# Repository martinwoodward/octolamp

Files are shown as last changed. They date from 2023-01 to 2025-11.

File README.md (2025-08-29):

# Octolamp
A 3D printable, GitHub infused, WiFi enabled smart light powered by [WLED](https://kno.wled.ge/) and compatible with [Home Assistant](https://www.home-assistant.io/)

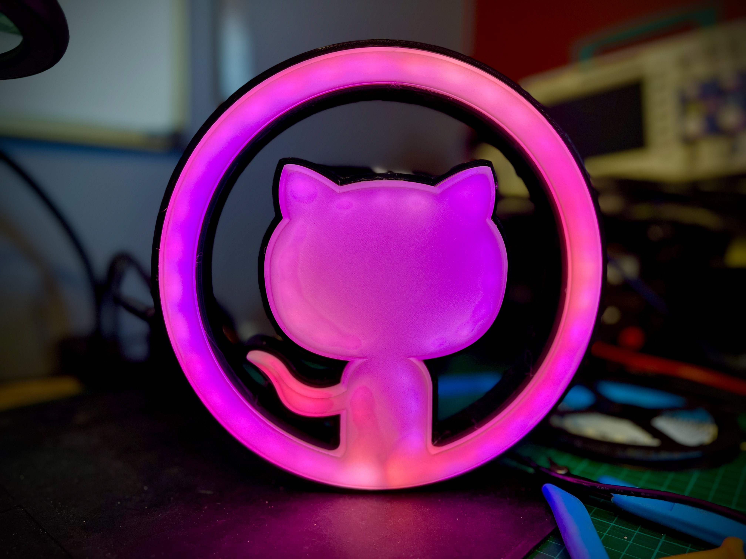
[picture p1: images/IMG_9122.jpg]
Picture of a fully constructed Octolamp


### Components

To build the Octolamp, you'll need access to a 3D printer, soldering iron and the following components:

- [Black PLA Filament](https://amzn.to/3CTo54W) (for the base) - [[US](https://amzn.to/3CTo54W)] [[UK](https://amzn.to/3w7fCXX)]
- [White PLA Filament](https://amzn.to/3GKObIz) (for the inner body and reflector) - [[US](https://amzn.to/3GKObIz)] [[UK](https://amzn.to/3XBNVSM)]
- WS2812B LED Strip, 60 LEDs per meter, just under 2m worth but usually sold in spools of 5m - [[US](https://amzn.to/3XwWnCT)] [[UK](https://amzn.to/3QKIzm6)]
- ESP8266 NodeMCU D1 Mini Module (or similar clone or other WLED compatible device) - [[US](https://amzn.to/3koQwS0)] [[UK](https://amzn.to/3kmp473)]
- USB lead (Micro or Type-C depending on the model of D1 Mini you have purchased, usually Micro-USB) [[US](https://amzn.to/3CTpqsl)] [[UK](https://amzn.to/3XxulY2)]

If you are looking for recommended links to buy these somewhere locally then please see [Purchasing Links](#purchasing-links) below.

Assuming you already have the PLA filament and a spare USB lead, the construction cost for the electrical components works out at <$20 per lamp.

### Instructions

The lamp itself consists of 3 printable parts, printed in regular PLA on a printer with greater than a 210mmx210mm print bed (the popular [Ender 3](https://amzn.to/3CRwSUQ) or [Prusa i3](https://amzn.to/3ZxlHdI) should both work, this was tested with an [Ender 3 S1](https://amzn.to/3CRwSUQ))

All models are designed to be printed without supports. I used a 10% gyroid infill.

The 3 components are:
- [Black base](models/octolamp_black_outer.stl)
- [White reflector](models/octolamp_white_reflector.stl)
- [White inner](models/octolamp_white_inner.stl)

When constructed they snap-fit together as shown.

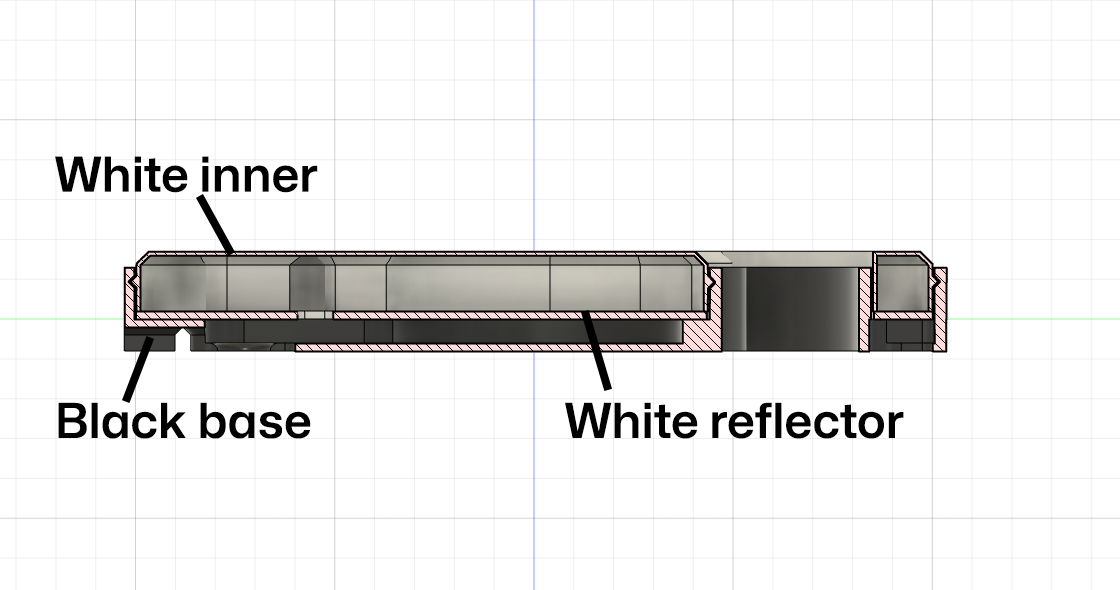
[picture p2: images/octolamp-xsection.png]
Cross-section of the Octolamp


When you have assembled your 3d printed parts you can begin contruction.

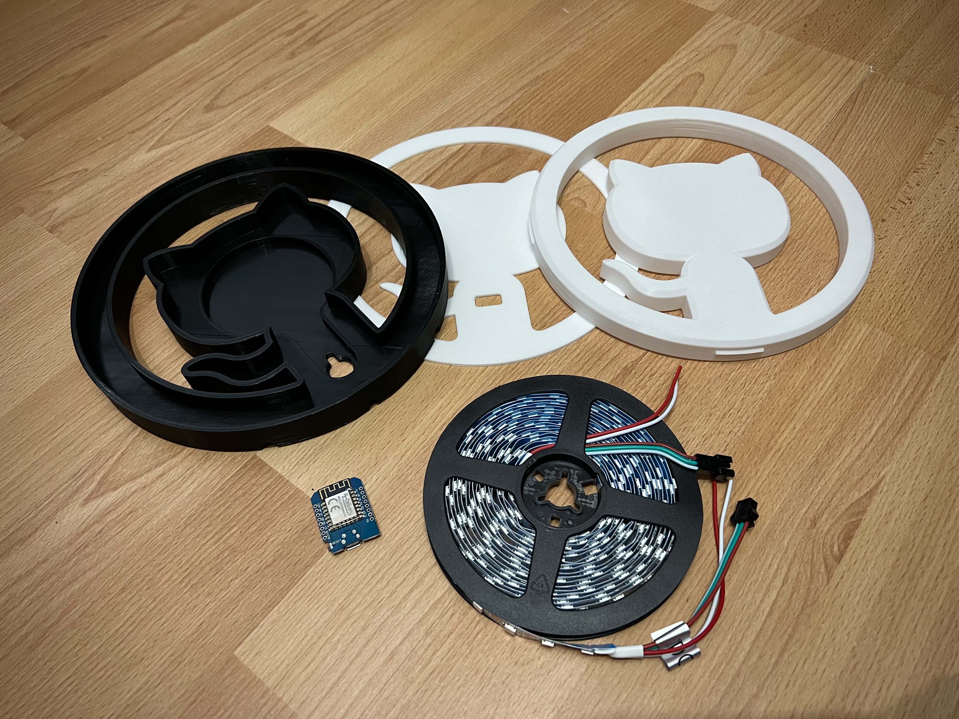
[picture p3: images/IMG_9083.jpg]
Component parts for the Octolamp build


#### Step 1 - Install WLED

First, you'll want to flash your D1 Mini device with [WLED](https://kno.wled.ge/) and then configure it to connect to your WiFi network. the [WLED project](https://kno.wled.ge/) is an open source firmware for many embedded devices that allow you to create beautiful LED displays and network them together. There are controller apps for iOS and Android and it is also fully compatible with the popular [Home Assistant](https://www.home-assistant.io/) software meaning that once built you can control your lamp from anywhere and build any number of automations so that it flashes when someone stars your GitHub repo, changes color when your build breaks or switches on and off with your office lights. 

Note that for large LED displays you can need significant power, you'll also likely want a controller that has a level shifter to send a reliable 5v signal for data to your LED strip. However as we're only powering 100 or so LEDs you can get away with pulling the power and data directly from the pins of an inexpensive D1 Mini.

The quickest and easiest way to install WLED on your D1 Mini is to plug it into the USB socket on your computer and then visit the [WLED web installer site](https://install.wled.me/).

- [https://install.wled.me/](https://install.wled.me/)

Flash the device with the latest build of WLED, configure the device to connect to your WiFi network and then you are ready to go.

#### Step 2 - Stick the LED Strip to the White Inner

The White Inner component acts as the guide for the flexible LED strip as well as the diffuser for the lights which are stuck to the side. You only need the +5v, G and Data pins so snip off any additional power lines that might come with your strip or solder on new wires to the strip if yours didn't come with pre-soldered wires.  Remove the plastic from the adhesive backing and start sticking at the bottom middle, looping around the outside then over to the inside and finally around the central part. Cut at the marked lines when you are finally done. Depending on your LED strip, the central part may require some additional adhesive, such as PLA friendly glue, to remain in place due to the reverse bend going from Octocat's body to head.

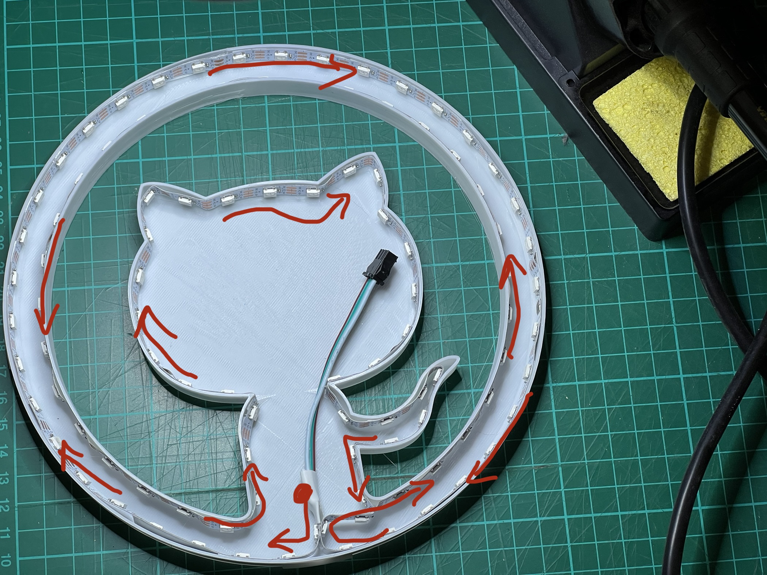
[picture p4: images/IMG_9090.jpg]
Path of the LED strip


When finished you should have around 100 LEDs in your lamp, but it's worth counting at this point as you'll need the exact number later (depending how I did my sticking I've used anything from 99 to 105)

#### Step 3 - Add the Reflector
Next, feed the wires through the hole in the reflector. If you are using plugs to connect your strip and controller then you can do this at any time but if you are soldering the strip directly to the controller then you need to do it now.

#### Step 4 - Solder LED Strip to D1 Mini
Rather than use plugs, I solder my strip directly to my D1 Mini, but you can use connectors if you wish.  Connect the +5v and G lines to the corresponding pins on the D1 Mini and the data line to D4 (just above the +5v and G pins).

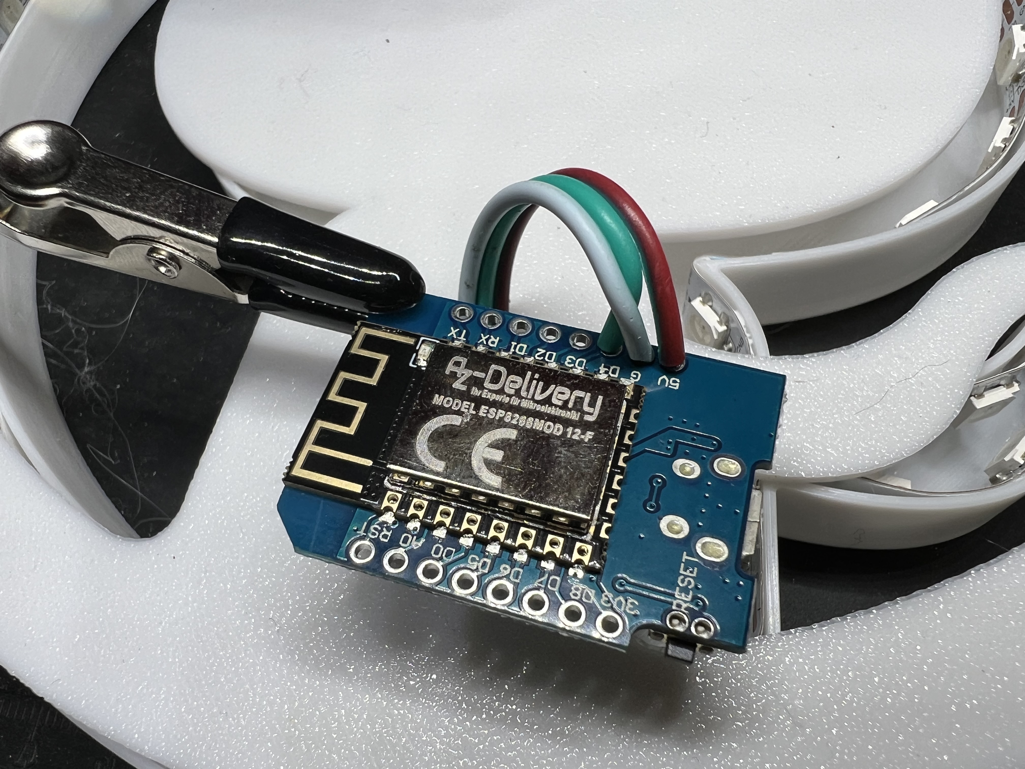
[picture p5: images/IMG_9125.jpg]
The wires from the LED strip soldered to the D1 Mini


#### Step 5 - Assemble
Next up, feed your USB lead through the back of the black outer body and connect it to your D1 Mini.  Place the D1 Mini in the small inlaid portion in the center of the lamp. Then drop in the reflector and finally place the white inner onto it, and snap fit into the black outer body. This should force the white reflector down which then also secures the electronics in place.  Power up your device and at this point about half of your LEDs should be glowing orange.

#### Step 6 - Connect to WLED and configure display
All the rest of the configuration is configuring WLED for your device.  Connect using the IP address from installation time, then go to Config, LED Preferences and update the Length of the LED strip to be the number of LEDs you installed in Step 2 (for me that's typically between 99 - 105).  When you press Save the rest of your LEDs should be glowing orange.

You can now configure your light display with the amazing flexibility of WLED. Once you have your favorite setting, store it as a preset and then go back to the LED Preferences and scroll down to Defaults where you can set which preset it displayed when the lamp is powered on (i.e. Preset 1 instead of the default orange in Preset 0)

#### Step 7 - Share your makes!
That's it!  You are now done but I'd love to see pictures of your built and assembled lamps.  Feel free to share pictures of them [in discussions here](https://github.com/martinwoodward/octolamp/discussions) or on social media and tag me on them [martinwoodward@hachyderm.io](https://hachyderm.io/@martinwoodward) on Mastodon or [@martinwoodward](https://twitter.com/martinwoodward) on Twitter and other socials

### Notes

I've tried to make the model super flexible so it includes ways to mount the lamp to a wall and different USB cable routing options.

The copyright for the invertocat logo belongs to GitHub. For acceptable use of that logo see the [GitHub logo usage guidelines](https://github.com/logos).

### Purchasing Links
The fun part of this project is making it yourself, the lamp isn't officially sold pre-assembled (and the license is non-commercial use only so they shouldn't be doing that).  But if you want to buy the components to make this them then the following components have been used and recommended by community members. Note some of these links make use of affiliate programs but they should always be linking to components the community trust.

#### United States
- [Black PLA Filament](https://amzn.to/3CTo54W) (for the base)
- [White PLA Filament](https://amzn.to/3GKObIz) (for the inner body and reflector)
- [WS2812B LED Strip, 60 LEDs per meter](https://amzn.to/3XwWnCT), just under 2m worth but usually sold in spools of 5m 
- [ESP8266 NodeMCU D1 Mini Module](https://amzn.to/3koQwS0) (or similar clone or other WLED compatible device)
- [Ender 3](https://amzn.to/3YjmLkD) S1 3D Printer

#### United Kingdom
- [Black PLA Filament](https://amzn.to/3w7fCXX) (for the base)
- [White PLA Filament](https://amzn.to/3XBNVSM) (for the inner body and reflector)
- [WS2812B LED Strip, 60 LEDs per meter](https://amzn.to/3QKIzm6), just under 2m worth but usually sold in spools of 5m 
- [ESP8266 NodeMCU D1 Mini Module](https://amzn.to/3kmp473) (or similar clone or other WLED compatible device)
- [Ender 3](https://amzn.to/3xcwoW9) S1 3D Printer

#### Singapore
- [WS2812B LED Strip, 60 LEDs per meter](https://s.lazada.sg/s.0zKLk), just under 2m worth but usually sold in spools of 5m 
- [ESP8266 NodeMCU D1 Mini Module](https://shp.ee/9gxtxxn) (or similar clone or other WLED compatible device)

#### Australia
- [WS2812B LED Strip, 60 LEDs per meter](https://www.jaycar.com.au/duinotech-arduino-compatible-w2812b-rgb-led-strip-2m/p/XC4390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) contains 2m, with 120 LEDs with connectors installed at ends and wires with connector for soldering to board
- [ESP8266 Wi-Fi D1 Mini Module](https://www.jaycar.com.au/duinotech-wi-fi-mini-esp8266-main-board/p/XC3802) or similar clone or other WLED compatible device. Note: This option has pre-installed IO header strips so some desoldering may be required

### Link to these instructions
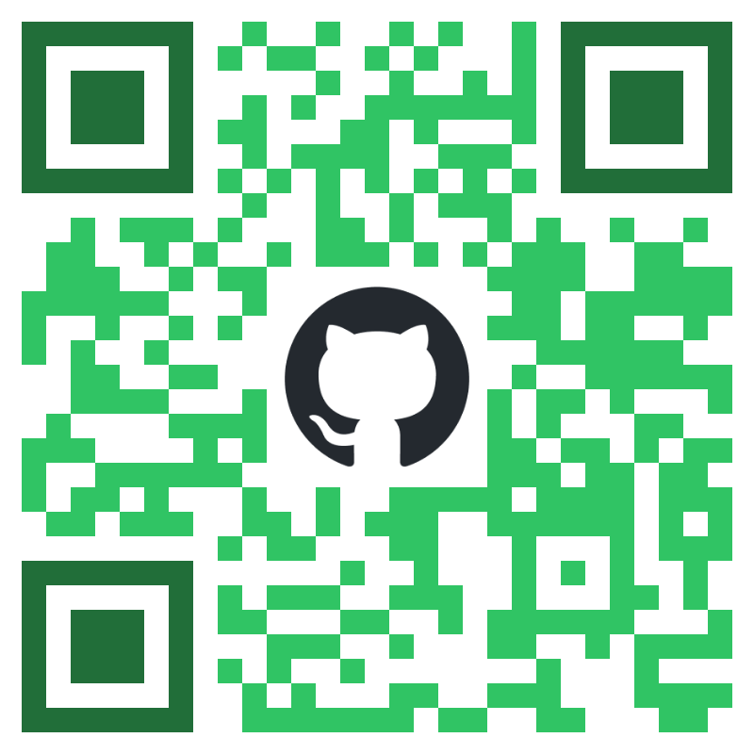
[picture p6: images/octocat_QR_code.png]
QR Code to these instructions


Instructions: https://github.com/martinwoodward/octolamp

An 85% scale of the Lamp is available [here](models/octolamp_multipart_A1_mini.3mf) for those with smaller print beds.

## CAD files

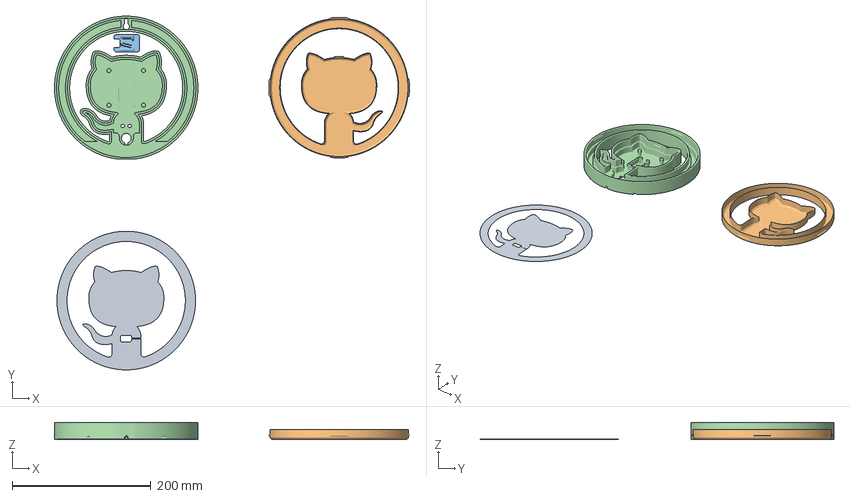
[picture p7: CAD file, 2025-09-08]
models/octolamp_multipart_mini_sparkle_motion.3mf
512.2 x 510.4 x 25.0 mm
White Reflector.stl
White Inner.stl
Black Outer Sparle Motion Top.stl
Black Bottom Mini Sparkle Motion.stl

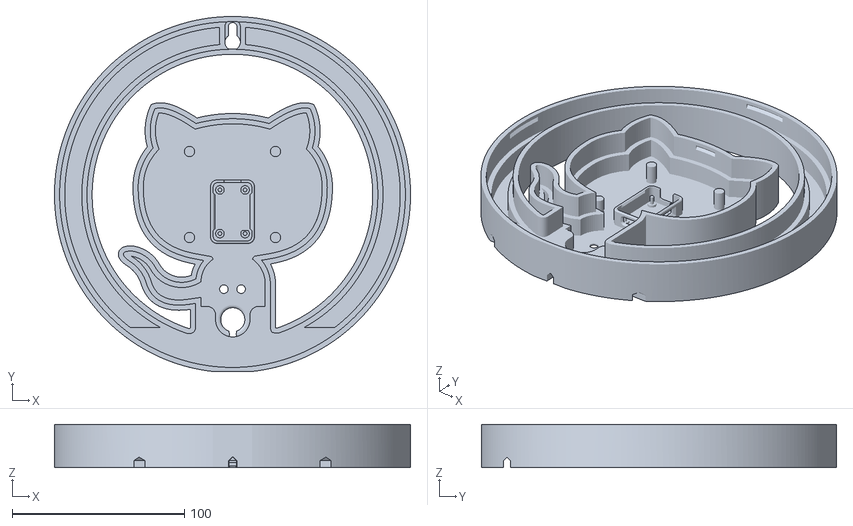
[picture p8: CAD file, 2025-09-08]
models/octolamp_black_outer_mini_sparkle_motion.stl
207.0 x 206.4 x 25.0

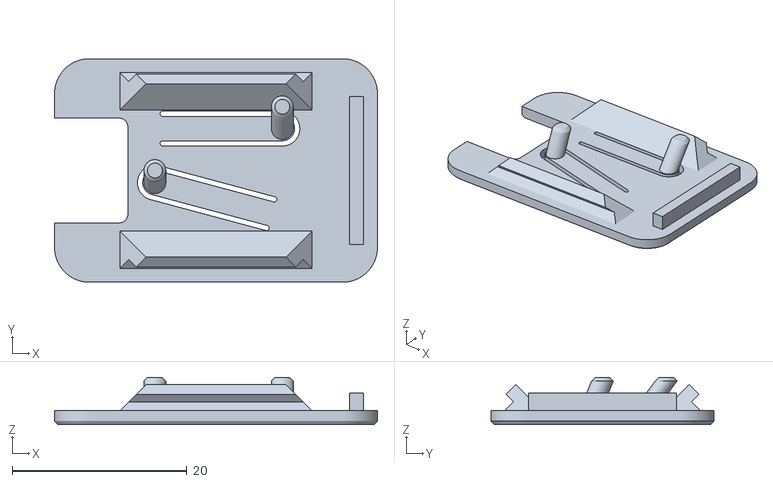
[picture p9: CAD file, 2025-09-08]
models/octolamp_black_outer_mini_sparkle_motion_top.stl
37.0 x 25.6 x 5.40

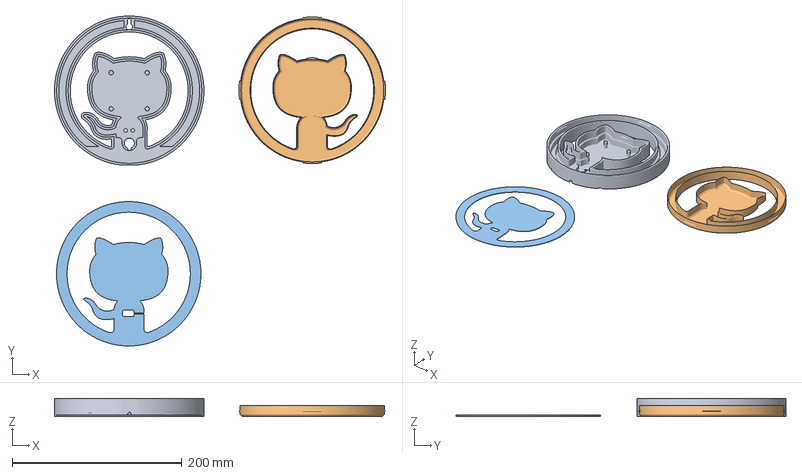
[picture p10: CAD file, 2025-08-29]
models/octolamp_multipart_A1_mini.3mf
389.6 x 388.4 x 21.2 mm
Black Outer.stl
octolamp_white_inner.stl
octolamp_white_reflector.stl

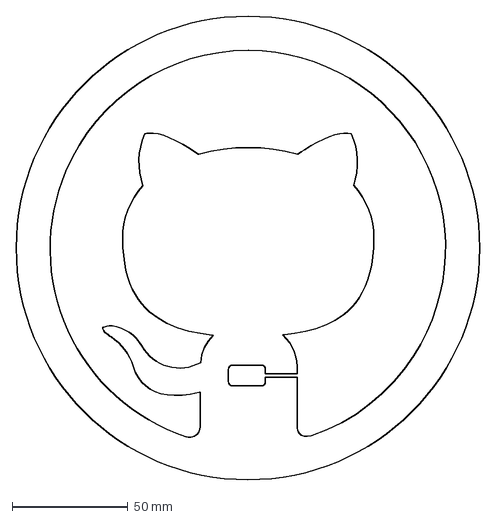
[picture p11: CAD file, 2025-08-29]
models/octolamp_white_reflector_laser.dxf
200.0 x 200.0 mm

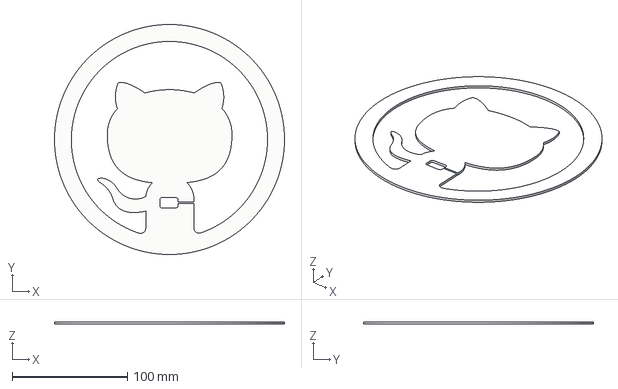
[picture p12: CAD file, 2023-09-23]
models/octolamp_white_reflector.3mf
200.0 x 200.0 x 2.00 mm

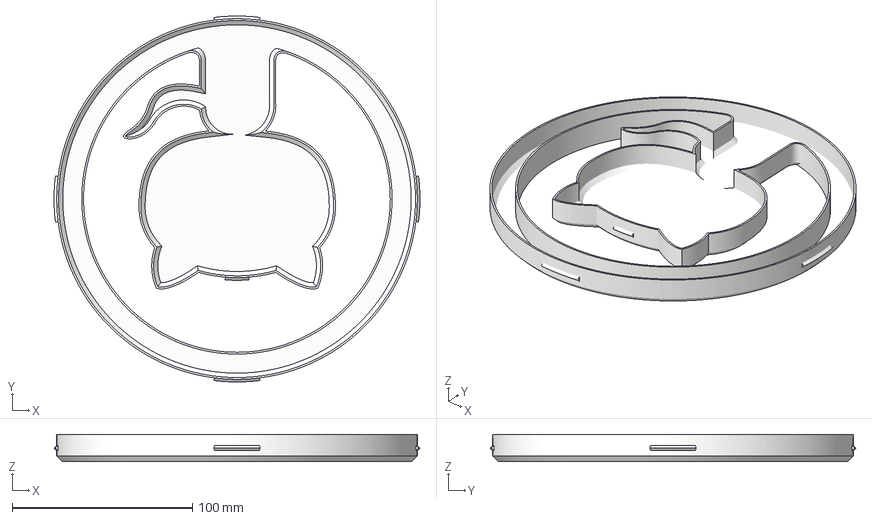
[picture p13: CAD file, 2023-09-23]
models/octolamp_white_inner.3mf
203.0 x 203.0 x 15.0 mm

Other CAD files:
models/octolamp_black_outer.3mf
models/octolamp_multipart.3mf
models/octolamp.f3d
models/octolamp_black_outer.stl
models/octolamp_white_inner.stl
models/octolamp_white_reflector.stl

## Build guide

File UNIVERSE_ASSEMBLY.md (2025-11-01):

# Assembling Your Octolamp Kit

Your Octolamp kit includes all the components you need to assemble your very own Octolamp! Follow these step-by-step instructions to get your lamp up and running.

You can find a video version of this tutorial here: https://youtu.be/Ya8gMkDxdD4 

Powered by an [Adafruit Sparkle Motion Mini](https://www.adafruit.com/product/6314) microcontroller, your Octolamp features an LED strip that is smarter than it may first appear.

## What is Included
- [Black base (Sparkle Motion Edition)](https://github.com/martinwoodward/octolamp/blob/main/models/octolamp_black_outer_mini_sparkle_motion.stl)
- [Black Controller cover](https://github.com/martinwoodward/octolamp/tree/main/models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)
- [White LED Holder](https://github.com/martinwoodward/octolamp/blob/main/models/octolamp_white_inner.stl)
- [White reflector](https://github.com/martinwoodward/octolamp/blob/main/models/octolamp_white_reflector.stl)
- Screwdriver
- [Adafruit Sparkle Motion Mini Microcontroller](https://www.adafruit.com/product/6314)
- USB cable
- LED cable
- LED strip (IP30 60 LED's per metre)
- Cable tie

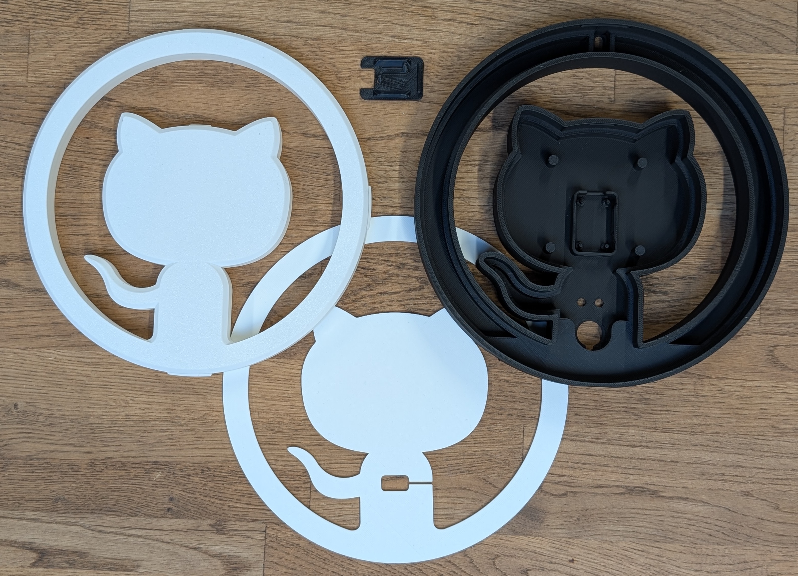
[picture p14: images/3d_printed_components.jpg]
3D printed components of the Octolamp including white inner shell, black outer cover, black base, and white reflector arranged on a surface

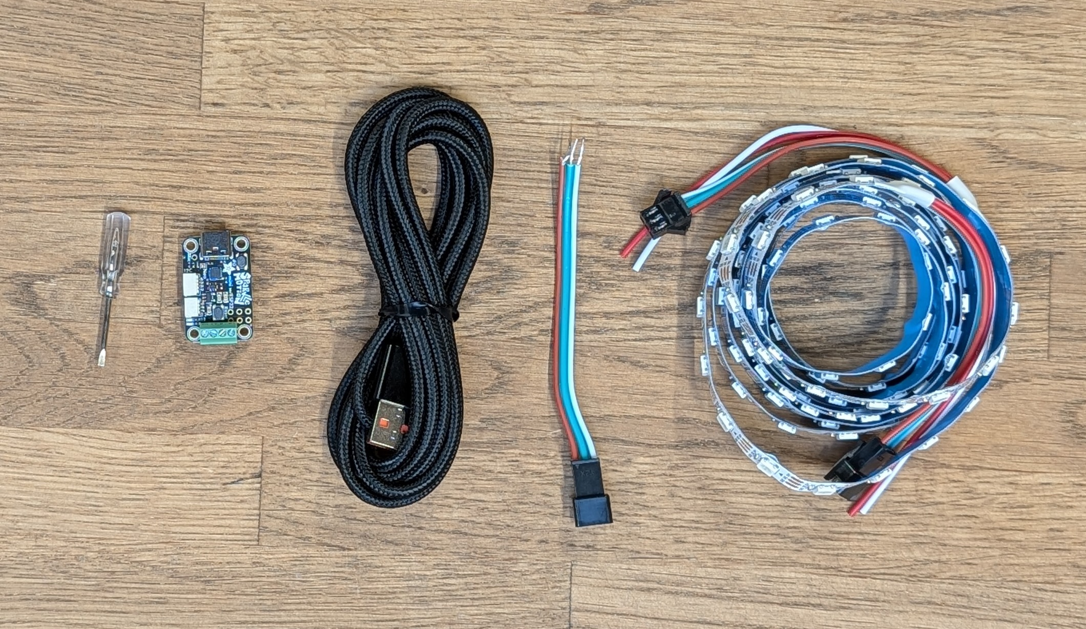
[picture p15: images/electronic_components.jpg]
Electronic components for the Octolamp including microcontroller board, USB cable, LED cable, and LED strip laid out ready for assembly


## Step 1: Connect the LED Cable to the Microcontroller
1. Use the screwdriver to loosen the first, third, and fourth terminals on the microcontroller.
2. From left to right, insert the red, green, and white wires of the LED cable into the respective terminals.
3. Tighten the terminals using the screwdriver.

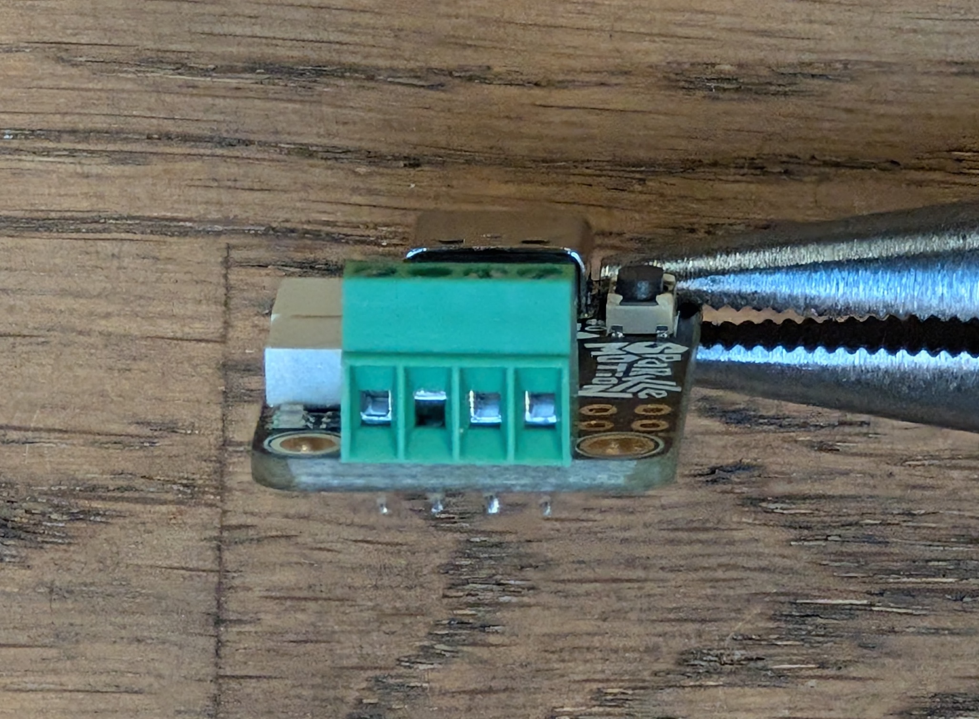
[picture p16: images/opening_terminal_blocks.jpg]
Close-up view of microcontroller terminal blocks being loosened with a screwdriver, showing the screw terminals in their open position ready for wire insertion

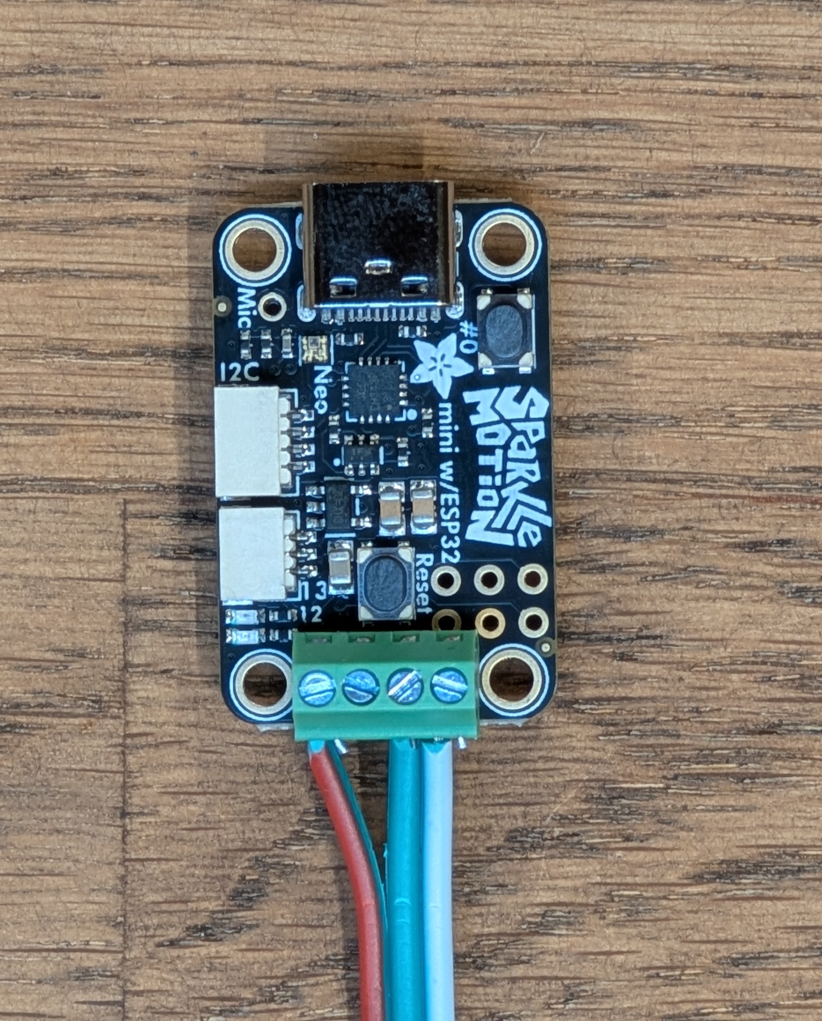
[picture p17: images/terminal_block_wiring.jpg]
Microcontroller terminal blocks with red, green, and white LED wires properly inserted and secured in the first, third, and fourth terminals from left to right


## Step 2: Test the LED Connection
1. **Important:** Uncoil the LED strip completely. Powering LEDs while tightly coiled will cause overheating.
2. Connect the LED cable to the LED strip. The cable should connect to the end with arrows pointing **away** from the connector.
3. Plug the USB cable into the microcontroller and connect to a power supply.
4. The LED's should now light up, either orange or green. 
5. If your LEDs do not turn on, check your connections.
6. If you are still having trouble, ask for help!

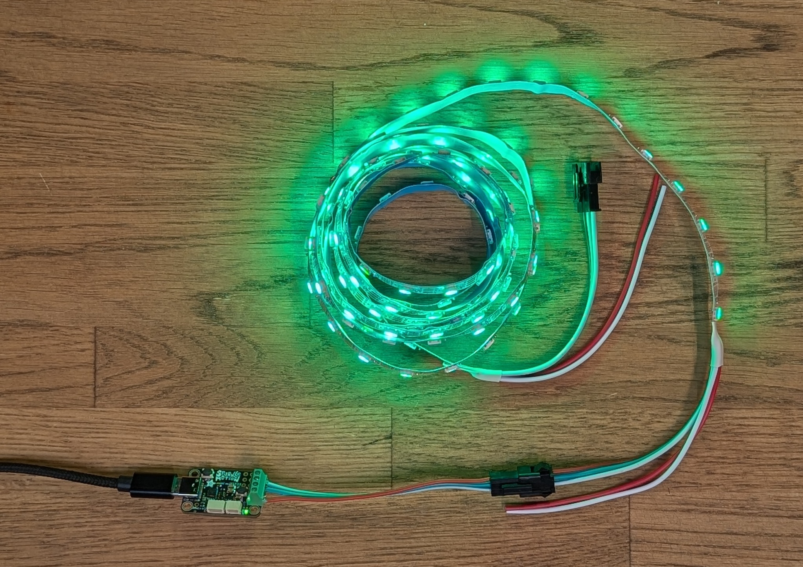
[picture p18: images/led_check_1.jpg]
LED strip connected and powered on, displaying bright green lights across most of the strip with the last few LEDs remaining off as expected during testing


## Step 3: Install the LED Strip Around the Outer Ring
1. Peel off the beginning of the LED strip's adhesive backing.
2. Press the start of the LED strip against the inside wall of the outer ring, at the base of Mona.
3. Continue around the inside wall of the outer ring, peeling off backing as you go.
4. Firmly press the strip against the ring frequently to ensure good adhesion.
5. Trim the backing paper if it gets in your way.
6. When you complete the outer ring, you should be back where you started at the base of Mona.

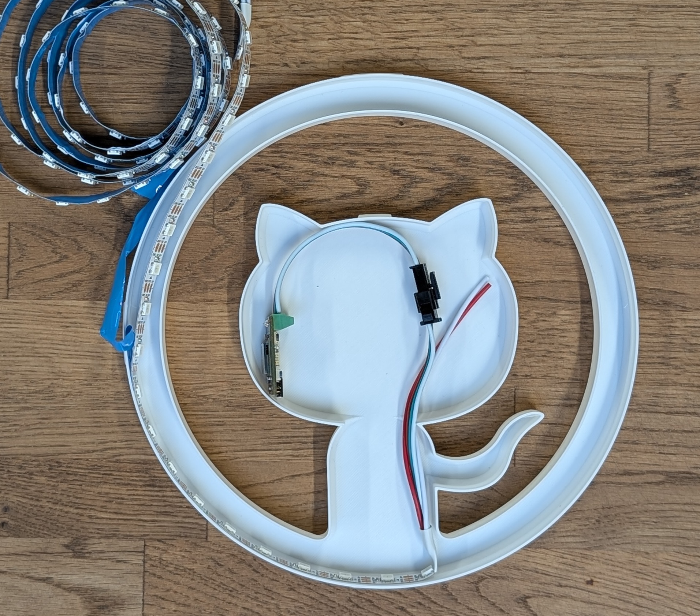
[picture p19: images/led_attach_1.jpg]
LED strip being attached to the inner wall of the white inner part, starting at the base near Mona with the adhesive backing being peeled away

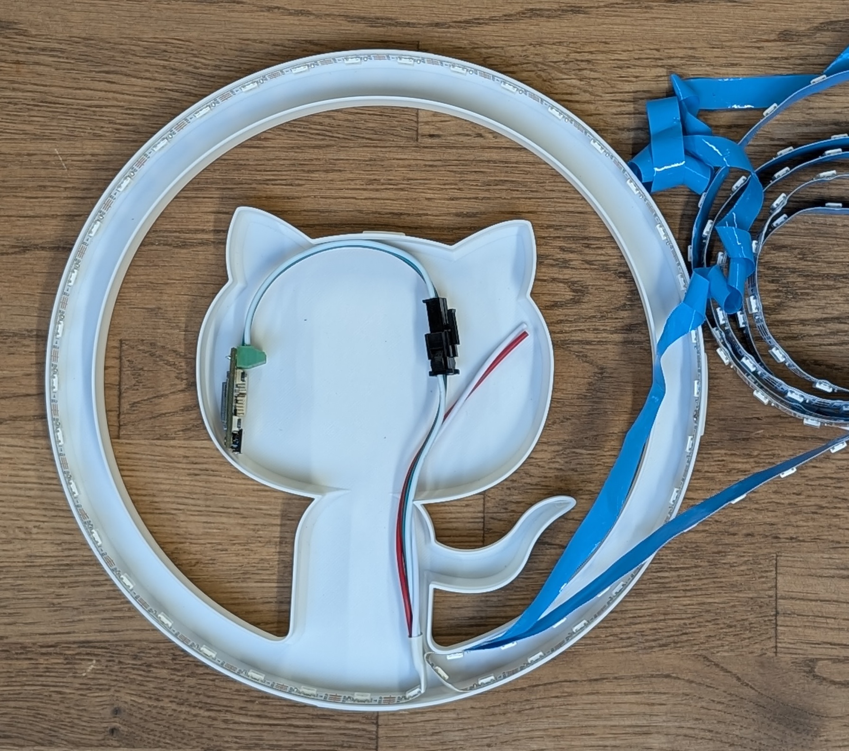
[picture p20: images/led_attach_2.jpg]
LED strip continuing around the inside wall of the outer ring, with hands pressing the strip firmly against the white inner part to ensure proper adhesion


## Step 4: Complete the LED Installation
1. Continue the LED strip along the inner ring wall, staying inside the part.
2. Follow the perimeter around the bottom of the ring and around Mona, finishing at her tentacle.
3. Cut off the excess LED strip where the installation is complete.
4. Connect the USB cable to the microcontroller and power supply.
5. All LEDs should now be bright green.
6. If LEDs do not turn on, check your connections.
7. If you are still having trouble, ask for help!

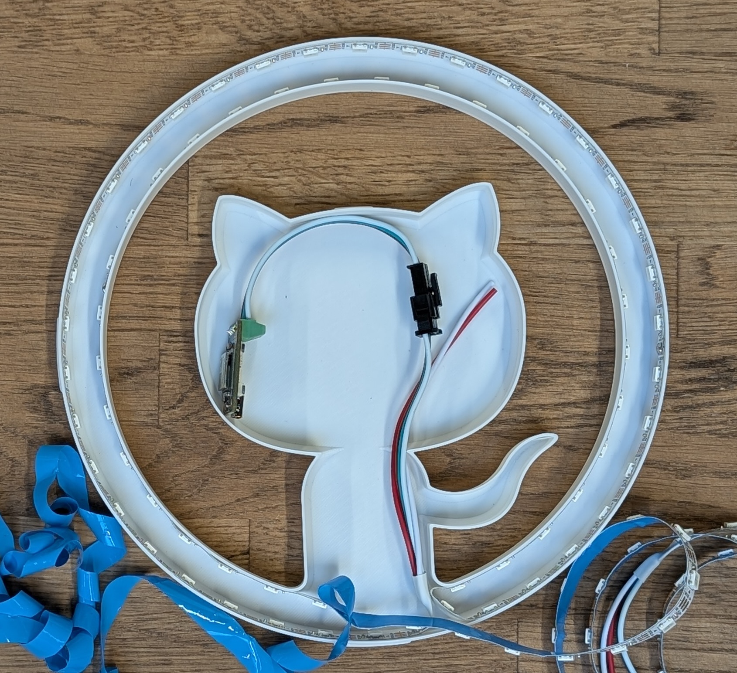
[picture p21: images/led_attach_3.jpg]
LED strip completing its path around the inner ring and following the perimeter of Mona, showing the final positioning near her tentacle

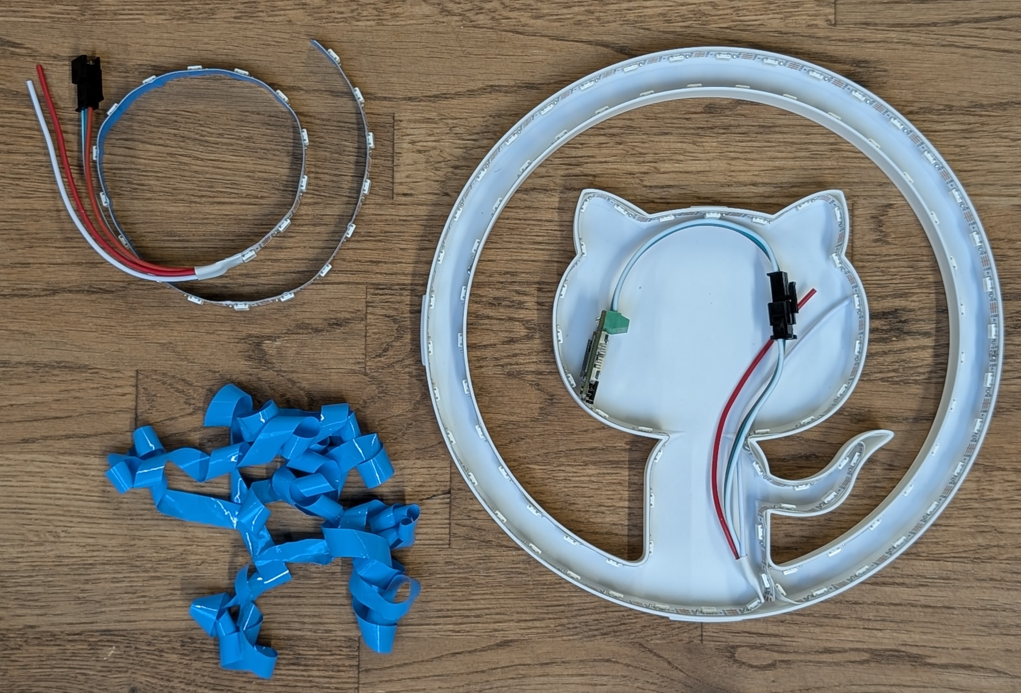
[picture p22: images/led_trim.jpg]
LED strip being carefully cut with scissors where the two ends meet after completing the circuit around the white inner part

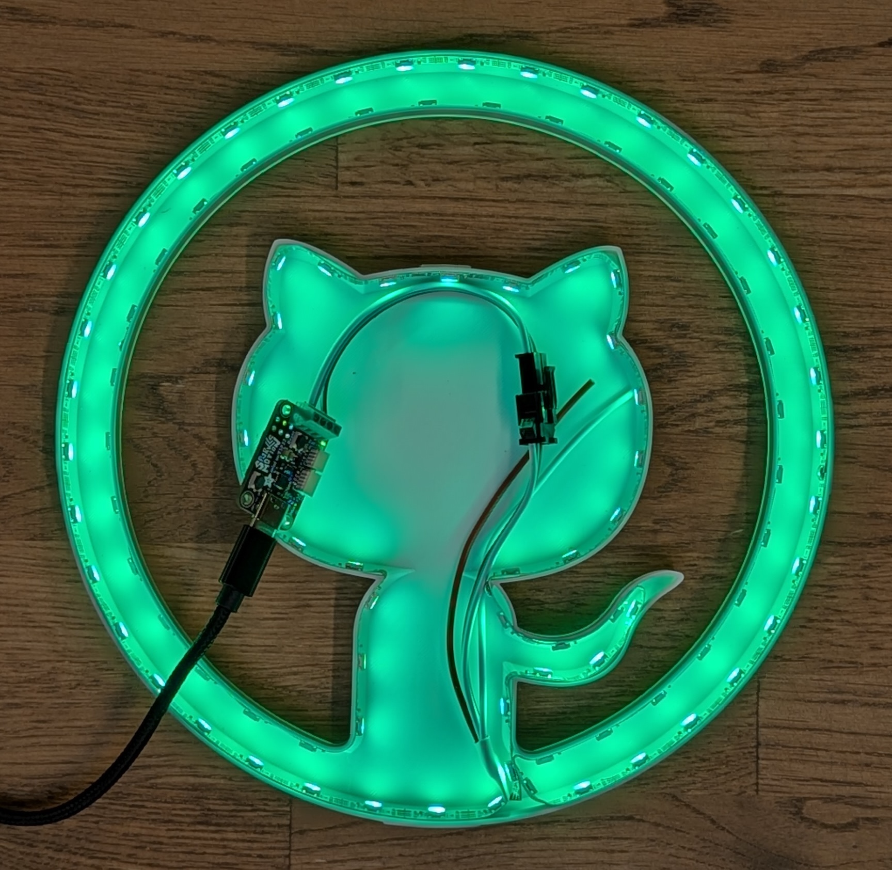
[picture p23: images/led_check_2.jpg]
Completed LED strip installation glowing bright green throughout the entire circuit around the white inner part, confirming proper connection and functionality


## Step 5: Final Assembly
1. Thread the wires through the slot in the white reflector, aligning Mona's tentacle with the corresponding features.
2. Flip the assembly over and insert the microcontroller into the center cavity of the black base.
3. Feed the USB cable through the hole in the base and connect it to the microcontroller.
4. Snap the black cover into place over the microcontroller.
5. Align the white reflector and inner parts with the black base, gently pressing everything together until fully seated.

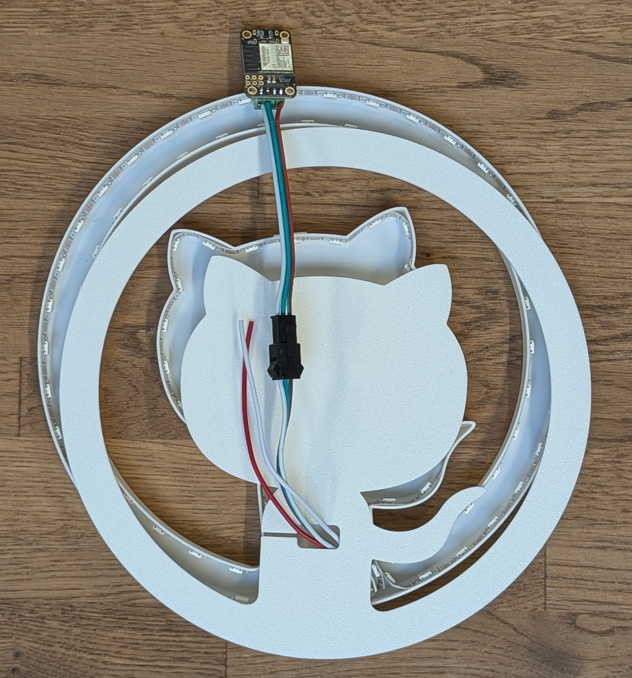
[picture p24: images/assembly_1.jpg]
White reflector with LED-equipped inner part being aligned with the black base, showing the proper positioning before final assembly

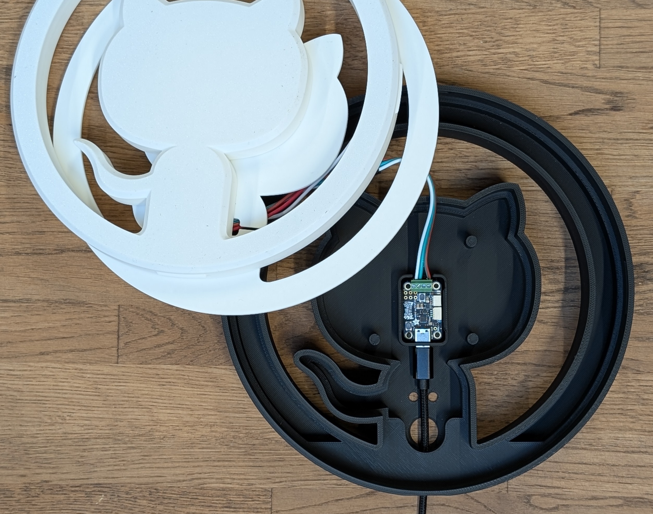
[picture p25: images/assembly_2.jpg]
Black outer cover being positioned over the white inner components, demonstrating the proper alignment during the assembly process

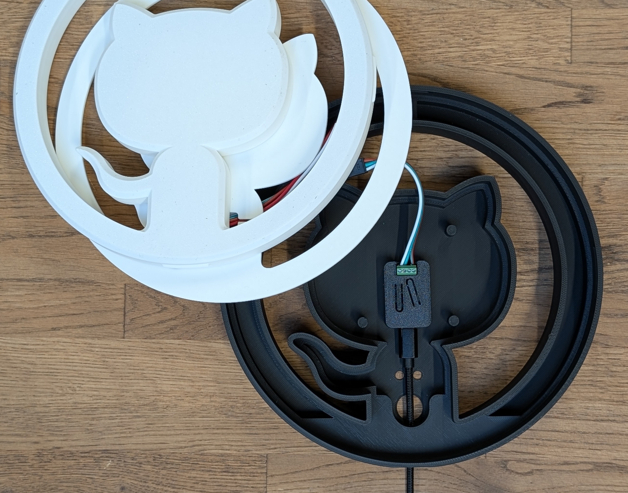
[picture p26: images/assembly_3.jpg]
Final assembly step showing all components being pressed together, with the black cover, white reflector, and base properly aligned and seated

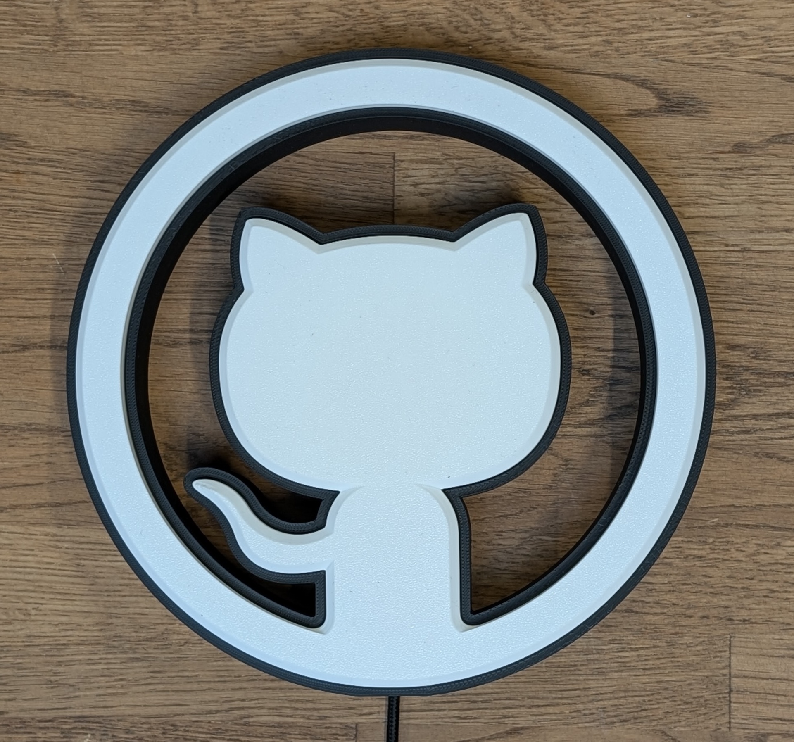
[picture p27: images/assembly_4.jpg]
Completed Octolamp assembly with all components fully seated and secured, showing the finished lamp ready for use


## Step 6: Final Test
1. Plug the USB cable into a power supply.
2. Your lamp should be fully illuminated with bright green light.
3. If LEDs do not turn on, check your connections.
4. If you are still having trouble, ask for help!

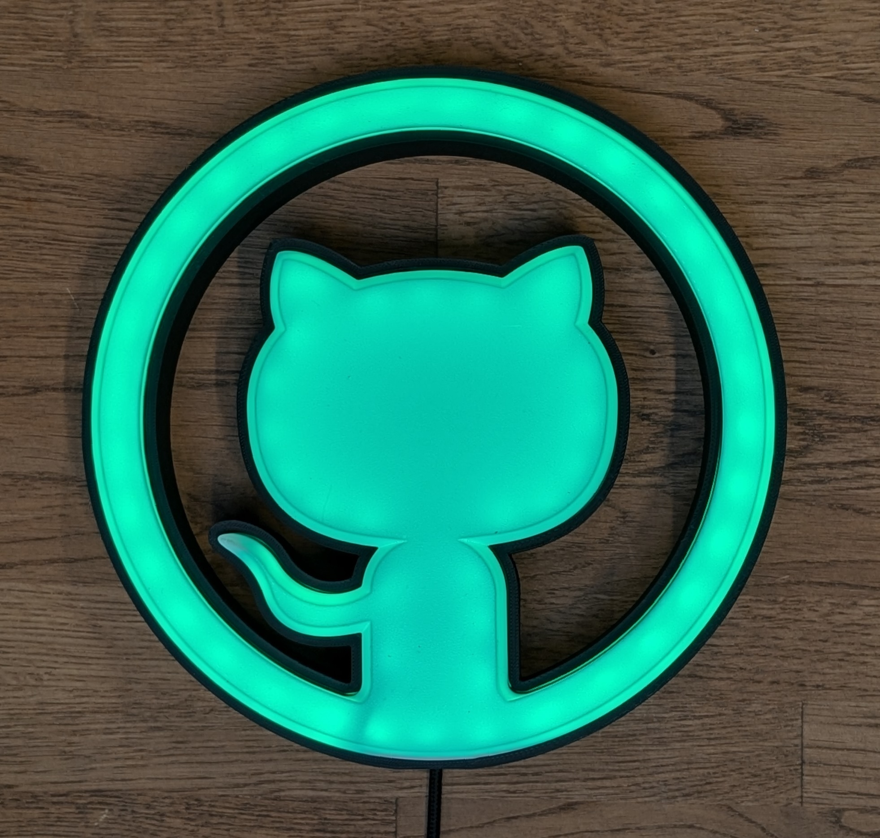
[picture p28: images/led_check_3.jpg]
Fully assembled Octolamp illuminated with bright green LEDs throughout the entire lamp, demonstrating the successful completion of the assembly process


## Step 7: Clean Up
1. Tidy your workspace, returning tools and disposing of LED strip trimmings.
2. Pack your completed lamp back into its bag.
3. Go explore what the rest of Universe has to offer!

When you get home, connect to the `WLED-AP` WiFi access point the lamp is broadcasting (password: `wled1234`) to customize its colors & behavior. Learn more about what’s possible at https://kno.wled.ge/ - there's a [Home Assistant integration](https://www.home-assistant.io/integrations/wled/) & more!

Share what you build with us.  You can post picture of your makes [here](https://github.com/martinwoodward/octolamp/discussions/categories/show-and-tell) or on social media! `#MadeAtGitHubUniverse`

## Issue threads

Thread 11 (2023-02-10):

Links and Resources in India

aaishikasb, 2023-02-10:
Hey @martinwoodward, thanks for building the Octolamp and making it available for all of us!
I have just started building mine and wanted to add a couple of resources for folks in India.
Should I add them here in this issue or can I push them to the README.md file?

martinwoodward, 2023-02-10:
Feel free to send over a PR for the Readme - thanks very much!

smalgin, 2023-05-23:
Awesome!

jaypk-git, 2023-05-23:
nice github!

zachbugay, 2023-05-23:
Hey this looks like some solid work!

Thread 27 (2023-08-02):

Provide smaller sized models for smaller 3D printers

sander1095, 2023-08-02:
I own a Prusa mini+ which can print ~180mm x 180mm x 180mm which is smaller than the required 210mm.

If this model and guide could be updated to also support a smaller model, I could print and set it up with my own printer!

martinwoodward, 2023-08-13:
Will take a look at creating a smaller version. In the meantime people have successfully scaled the model down in the prusia slicer and it's come out well so maybe give that a go in the meantime.

basvandesande, 2024-05-02:
on my Bambulab A1 mini,  I scaled the model down to 86% for both X and Y axis. I left the Z axis to 100%
This should allow me to fit in the electronics.  I'll share some pictures once the parts arrive (which should be tmrw).

sander1095, 2024-06-13:
Hey @basvandesande , any updates?

martinwoodward, 2024-06-20:
Awesome thanks @jgarverick

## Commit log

2023-01-16 Add models and basic instructions.
    [octolamp.f3d, octolamp_black_outer.stl, octolamp_white_inner.stl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]
2023-01-16 Show soldered pins
2023-02-09 Update README.md
    Added links to stores in Singapore selling LED strip and D1 Mini
2023-02-15 Updates based on feedback
    [octolamp.f3d, octolamp_black_outer.stl, octolamp_white_inner.stl]
2023-06-26 Add gap for wires in reflector
    Add a side gap for the wires in case people are soldering them
    in place but forget to do that before putting electronics in
    place. Why yes I may have made that mistake myself...
    [octolamp.f3d, octolamp_white_reflector.stl]
2023-06-30 Added lesson learnt with LED strip adhesive
2023-09-23 Adding 3mf exports of models
    [octolamp_black_outer.3mf, octolamp_white_inner.3mf, octolamp_white_reflector.3mf]
2024-04-02 Make backing deeper
    [octolamp.f3d, octolamp_black_outer.3mf, octolamp_black_outer.stl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]
2024-06-20 Adding 3mf file for Bambu A1 mini
    [octolamp_A1mini.3mf]
2024-06-20 Starting howto for scaled printing and LED application
2024-06-21 Collapsing doc and copying multipart 3mf for scale
    [octolamp_A1mini.3mf, octolamp_multipart_A1_mini.3mf]
2025-08-29 Add white reflector shape for laser cutting
    [octolamp_white_reflector_laser.dxf]
2025-09-08 Add version of base with mount for Adafruit Mini Sparkle Motion board
    [octolamp_black_outer_mini_sparkle_motion.stl, octolamp_black_outer_mini_sparkle_motion_top.stl, octolamp_multipart_mini_sparkle_motion.3mf]
2025-10-26 Add assembly instructions and images for Octolamp at Universe '25
2025-11-01 Revise Octolamp assembly instructions and links
    Updated the assembly instructions for the Octolamp kit, including links to components and clarifying LED testing steps.
